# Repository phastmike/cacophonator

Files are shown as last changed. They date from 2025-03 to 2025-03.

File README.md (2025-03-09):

# Cacophonator

This repository contains the [KiCad](https://www.kicad.org/) project of a try at recreating an instance of
**[the cacophonator](https://www.theremin.us/Circuit_Library/cacophonator.html)**
by Arthur Harrison. 

### Build iteration

#### V1 THT

- Using THT (Through-hole) components
- Designed for [JSL 166x116x70mm Box](https://www.leroymerlin.pt/produtos/caixa-estanque-10-boquilhas-153x102x67mm-ip66-cinzento-jsl-15918315.html)

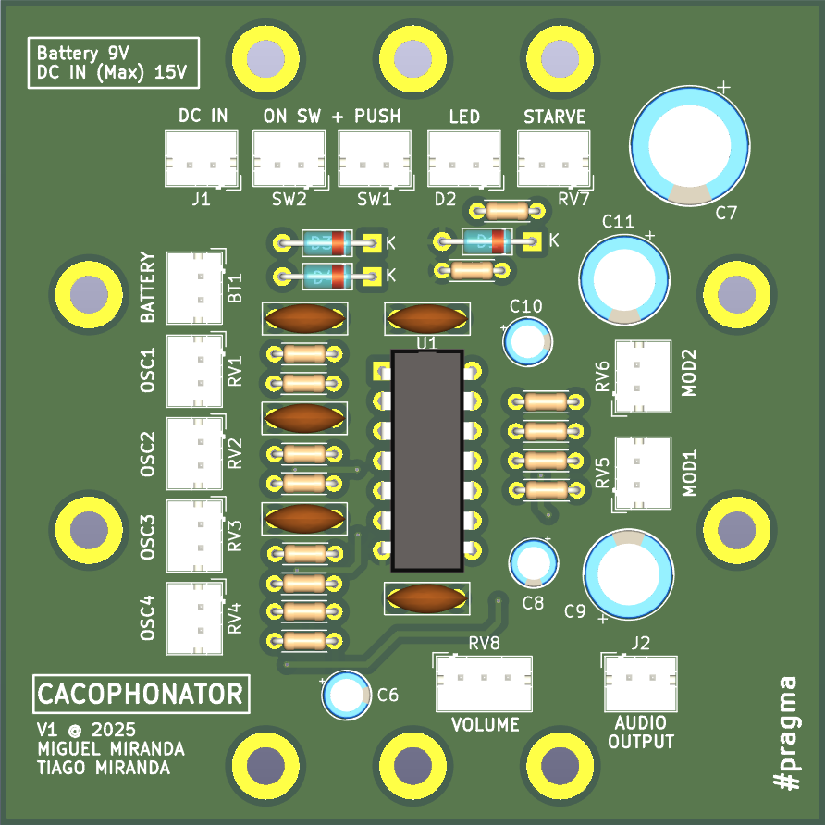
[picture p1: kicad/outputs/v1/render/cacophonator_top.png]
Latest


## Modifications to the original
 
- Added a potentiometer to control the output amplitude (volume)
   - Should be a **logaritmic (log) potentiometer**
- Added DC Input jack with diodes for multiple, concurrent, power sources
   - Battery (9V)
   - DC IN (9 or 12V))

## Notes

Designed with KiCad 9.0 

Top cover layout tryout

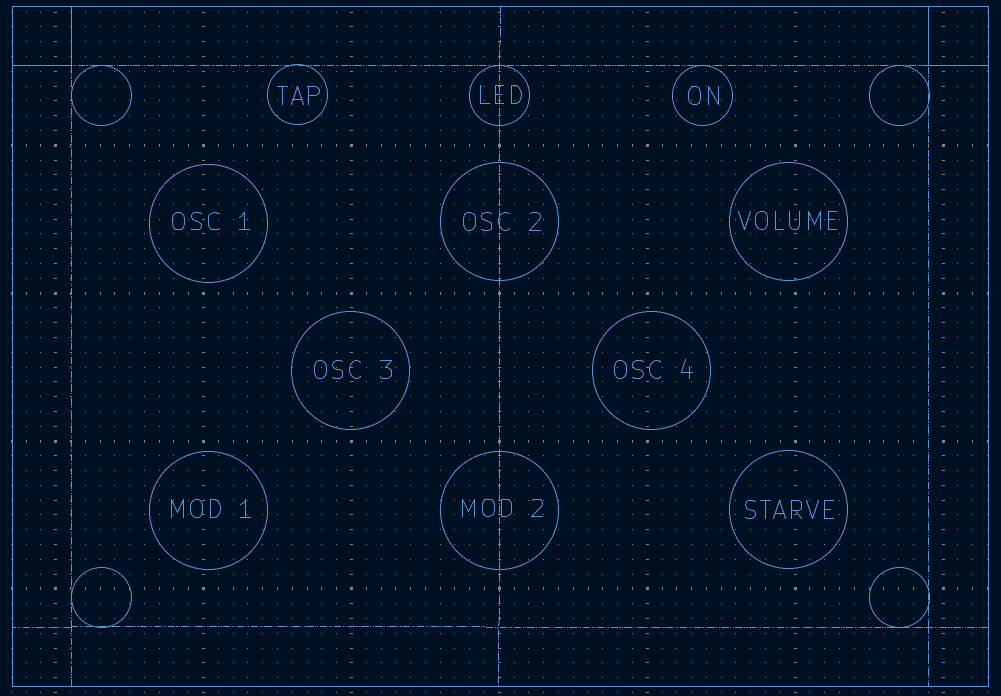
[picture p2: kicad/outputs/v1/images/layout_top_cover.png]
Layout 1


Box (166x116x70mm)

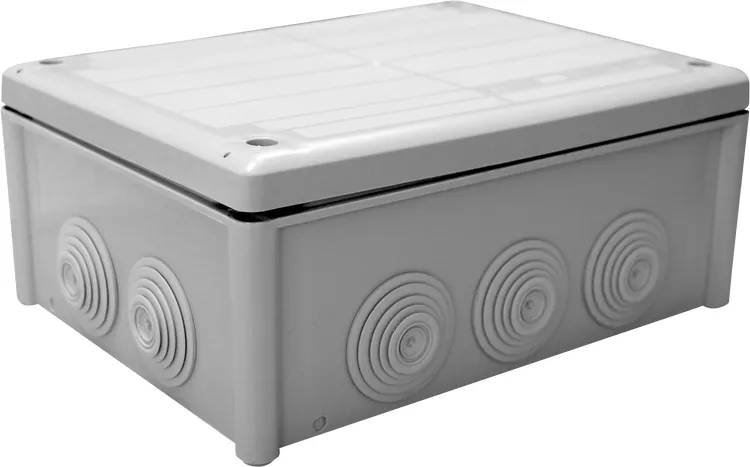
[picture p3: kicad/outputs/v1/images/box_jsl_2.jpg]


### BOM - Bill of Materials

[BOM](icad/outputs/v1/cacophonator-bom.ods)

### Links

- https://www.theremin.us/Circuit_Library/cacophonator.html
- https://syntherjack.net/catophonator/
- https://vitrolxul.mitiendanube.com/productos/cacophonator/
- http://analogmodularsystem.blogspot.com/2014/01/cacophonator-i.html
- https://milwaukeemakerspace.org/2011/09/cacophonator/
- https://beavisaudio.com/projects/cmossynthesizers/
- https://blacblob.qsdf.org/2018/10/03/cacophonator/
- https://static.flickr.com/100/312128991_4e7175fa40.jpg?v=0
- https://www.ti.com/lit/an/slyt336/slyt336.pdf?ts=1739280684395
- https://www.flickr.com/photos/53178019@N00/page2
- https://electro-music.com/forum/post-328159.html
- https://dimsos.dk/cacophonator/cacophonator-take-2-v8/
- https://www.matrixsynth.com/search/label/Cacophonator
- http://www.subtlenoisemaker.com/cacophonator_noir.html

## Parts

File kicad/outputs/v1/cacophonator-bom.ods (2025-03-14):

Reference | Value | Qty | Total | Price Unit | Note | Link
BT1 | 9V | 0 |  |  | JST 2mm | ---
C1,C2 | 2200pF (2.2nF) | 2 | 0.425 | 0.2125 | 15% Disc. AE | AlfaElektor
C3,C4,C5 | 0.01uF (100nF) | 3 | 0.3 | 0.1 |  | https://www.botnroll.com/pt/condensadores/171-condensador-100nf.html
C6,C9,C11 | 22uF | 3 | 0.2175 | 0.0725 | (1.45€/20) | AliExpress
C7 | 2200uF | 1 | 0.184 | 0.184 | (1.84€/10) | AliExpress
C8,C10 | 4.7uF | 2 | 0.375 | 0.1875 | (1.84€/10) | AlfaElektor
D1 | MUR210G* (1N4935G*) | 1 | 0.163 | 0.163 | 1N4934 OPT | https://www.botnroll.com/pt/diodos/919-diodo-retificador-1n4934.html
D2 | LED (Green) | 1 | 0.15 | 0.15 | Apt | https://www.botnroll.com/pt/5mm/2629-led-difuso-5mm.html
D3,D4 | 1N4004* (1N4001-x) | 2 | 0.162 | 0.081 | 1N4001 OPT | https://www.botnroll.com/pt/diodos/1651-diodo-1n4001.html
J1 | 5.5mm/2.1mm DC IN Jack plug | 1 | 0.4 | 0.4 |  | https://www.botnroll.com/pt/alimentacao-dc/1232-socket-dc-supply-male-55mm-25mm-with-onoff-switch-9mm.html
J2 | Jack 6.25mm Chassis Female | 1 | 0.55 | 0.755 | 15% Disc. AE | AlfaElektor
R1,R2,R3,R4,R5,R6,R7,R8,R11,R13 | 10k | 10 | 0.412 | 0.0412 |  | https://www.botnroll.com/pt/resistencias/179-resistencia-10k.html
R10 | 22 | 1 | 0.0422 | 0.0422 | 15% Disc. AE | AlfaElektor
R12,R14 | 100 | 2 | 0.0844 | 0.0422 | 15% Disc. AE | AlfaElektor
R15 | 560 | 1 | 0.0422 | 0.0422 | 15% Disc. AE | AlfaElektor
RV1,RV2,RV3,RV4,RV5,RV6 | 1M | 6 | 2.34 | 0.39 |  | https://www.botnroll.com/pt/potenciometros/5746-potenci-metro-linear-mono-met-lico-1m-125mw-veio-6mm-estriado.html
RV7 | 10k | 1 | 0.39 | 0.39 |  | https://www.botnroll.com/pt/potenciometros/5740-potenci-metro-linear-mono-met-lico-10k-125mw-veio-6mm-estriado.html
RV8 | 100k logaritmic | 1 | 0.39 | 0.39 |  | https://www.botnroll.com/pt/potenciometros/5743-potenci-metro-linear-mono-met-lico-100k-125mw-veio-6mm-estriado.html
SW1 | Switch | 1 | 0.65 | 0.65 | 1A or 3A | https://www.botnroll.com/pt/painel/882-interruptor-2a-250vac-toogle.html
SW2 | Pushbutton | 1 | 0.5 | 0.5 | 1A | https://www.botnroll.com/pt/painel/3154-1065-bot-o-de-press-o-spst-no-1a-250vac-preto.html
U1 | IC 40106 | 1 | 0.85 | 0.85 | 15% Disc. AE | https://www.ti.com/lit/ds/symlink/cd40106b.pdf?ts=1741259708515
DIP IC SOCKET 14PIN | - | 1 | 0.25 | 0.25 |  | https://www.botnroll.com/pt/sockets-ics/190-suporte-ic-14-pinos.html
JST 2mm 2 PIN SOCKET | Various | 13 | 1.8005 | 0.1385 | Incl.socket | https://www.botnroll.com/pt/jst/5029-conector-pcb-jst-ph-2-0mm-2-pinos.html
JST 2mm 2 PIN PLUG | Various | 13 | 0 | 0 |  | https://www.botnroll.com/pt/jst-molex/5024-cabo-jst-ph-2-0mm-20cm-2-pinos.html
JST 2mm 3 PIN SOCKET | Volume | 1 | 0.2 | 0.2 |  | https://www.botnroll.com/pt/jst/5029-3274-conector-pcb-jst-ph-2-0mm-2-pinos.html
JST 2mm 3 PIN PLUG | Volume | 1 | 0.4 | 0.4 |  | https://www.botnroll.com/pt/jst-molex/5024-3255-cabo-jst-ph-2-0mm-20cm-2-pinos.html
BATTERY PLUG 9V | Plug | 1 | 0.4 | 0.4 | 15cm cable | https://www.botnroll.com/pt/6lr61-9v-/738-suporte-para-pilha-9v.html
BATTERY HOLDER | Battery holder | 0 | 0 | 0.5 |  | https://www.botnroll.com/pt/6lr61-9v-/3182-suporte-de-pilhas-9v-com-fios-150mm.html
DC 2.1mm PLUG | DC IN | 0 | 0 | 0.3 |  | https://www.botnroll.com/pt/jack/1234-ficha-femea-alimentacao-dc-55mm-25mm-para-soldar-em-cabo-9mm.html
SCREWS M2.5 |  | 8 | 0.4 | 0.05 | Est. | ---
POTENTIOMETER CAP | VARIOUS OPTIONS | 8 | 2.4 | 0.3 |  | https://www.botnroll.com/pt/potenciometros/4600-knob-bot-o-para-potenci-metro-de-6mm-amarelo.html
LED CHASSIS HOLDER |  | 1 | 0.5 | 0.5 | 8 / 6 mm | ---
PCB (1/10) | PCBWay x10 (13.44€) | 1 | 1.35 | 1.35 |  | https://www.pcbway.com/project/OnlineGerberViewer.html
CAIXA | JSL J160B (166x116x70mm | 1 | 3.19 | 3.19 |  | https://www.leroymerlin.pt/produtos/caixa-estanque-10-boquilhas-153x102x67mm-ip66-cinzento-jsl-15918315.html
 |  |  | 19.5178

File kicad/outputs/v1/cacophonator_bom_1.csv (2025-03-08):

Reference | Value | Qty
BT1 | 9V | 1
C1,C2 | 2200pF | 2
C3,C4,C5 | 0.01uF | 3
C6,C9,C11 | 22uF | 3
C7 | 2200uF | 1
C8,C10 | 4.7uF | 2
D1 | MUR210G* | 1
D2 | LED | 1
D3,D4 | 1N4004* | 2
J1 | Jack-DC | 1
J2 | AUDIO OUTPUT | 1
R1,R2,R3,R4,R5,R6,R7,R8,R11,R13,RV7 | 10k | 11
R10 | 22 | 1
R12,R14 | 100 | 2
R15 | 560 | 1
RV1,RV2,RV3,RV4,RV5,RV6 | 1M | 6
RV8 | 100k log | 1
SW1 | POWER | 1
SW2 | CHARGE | 1
U1 | 40106 | 1

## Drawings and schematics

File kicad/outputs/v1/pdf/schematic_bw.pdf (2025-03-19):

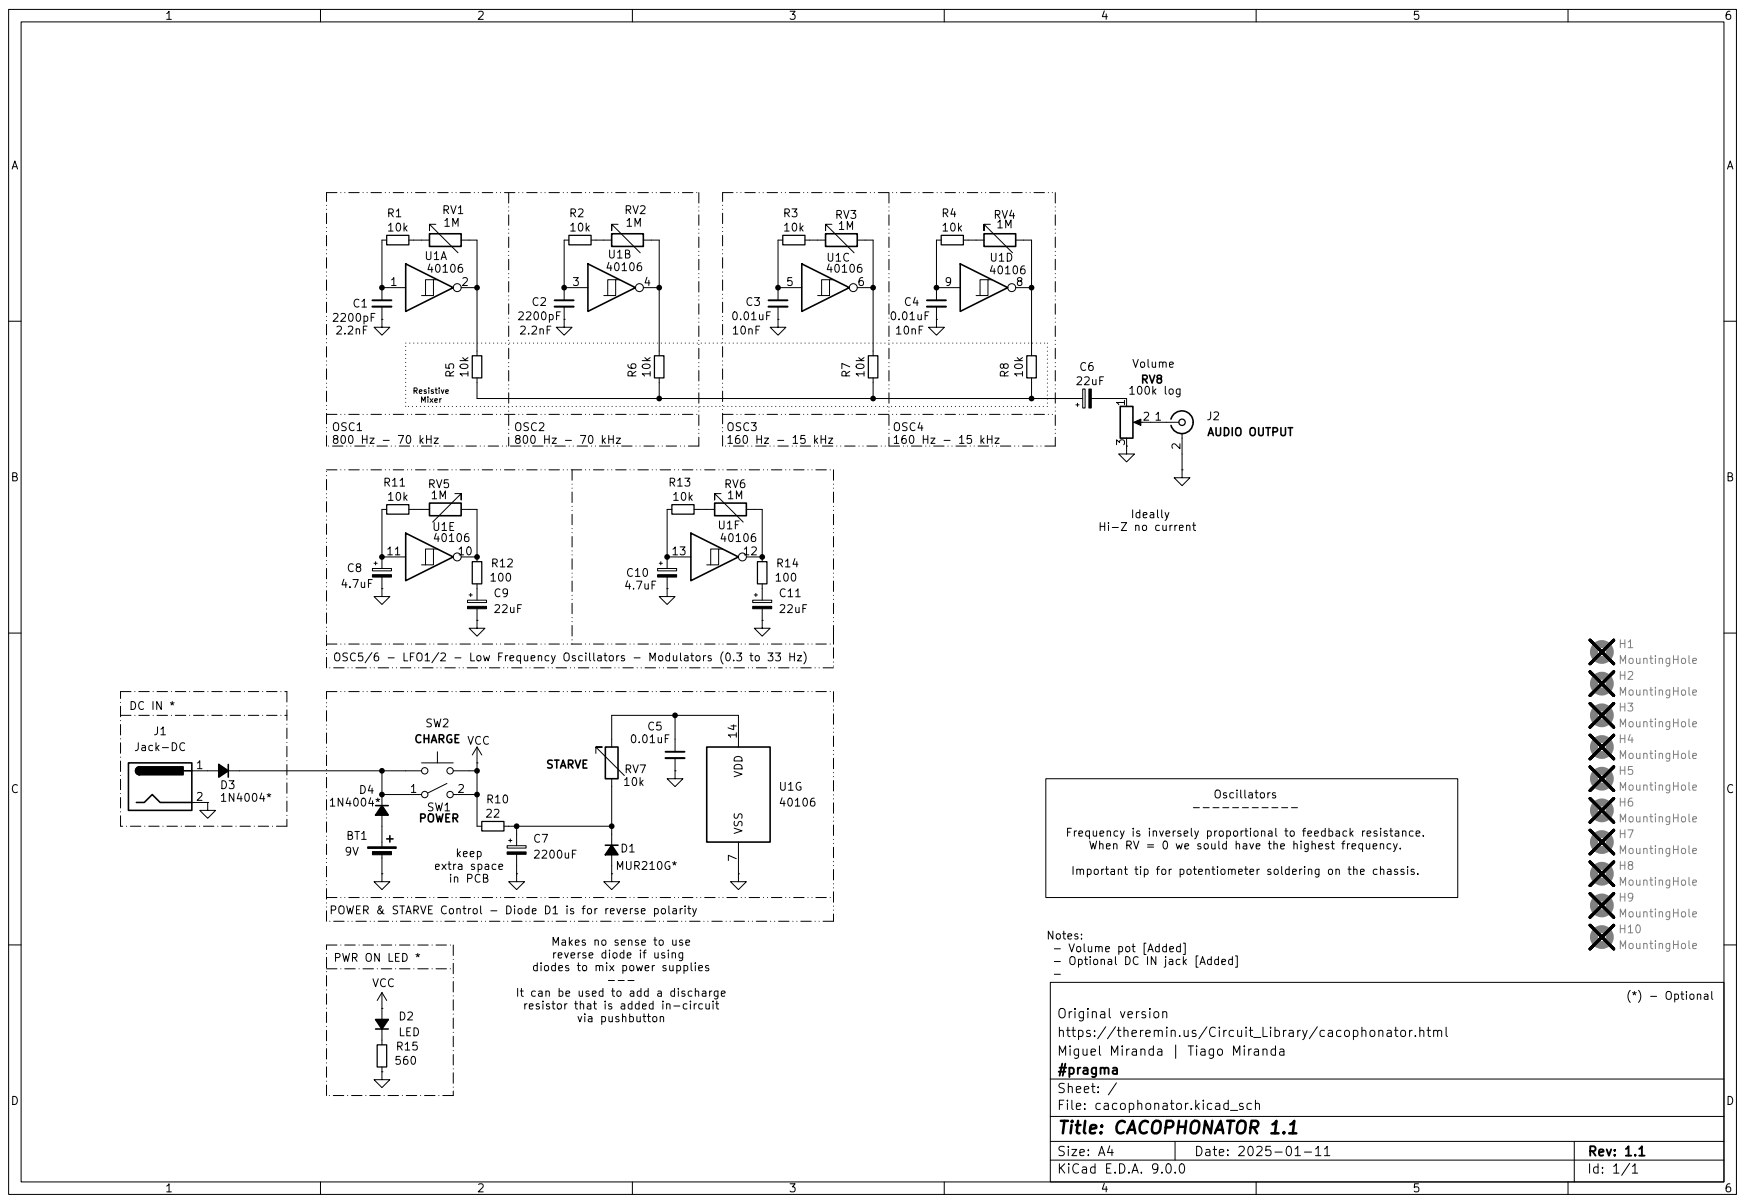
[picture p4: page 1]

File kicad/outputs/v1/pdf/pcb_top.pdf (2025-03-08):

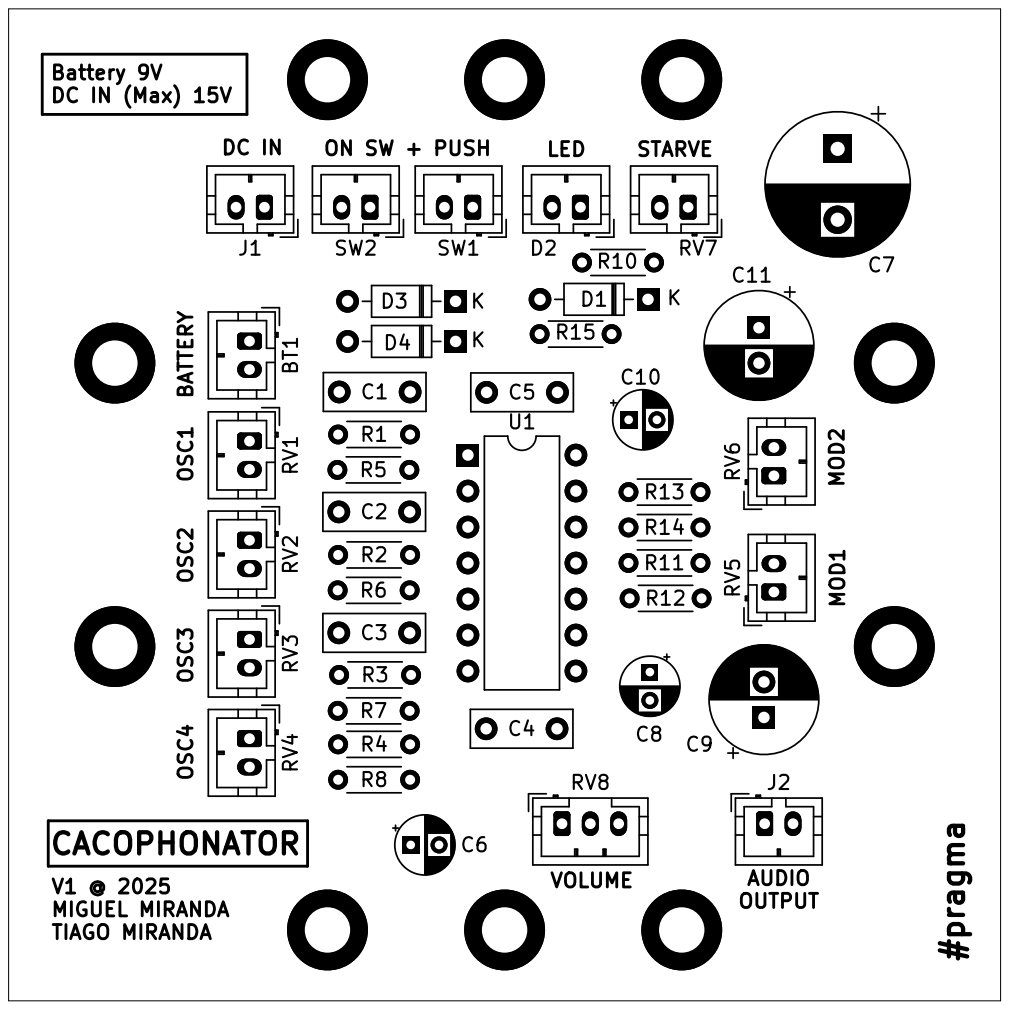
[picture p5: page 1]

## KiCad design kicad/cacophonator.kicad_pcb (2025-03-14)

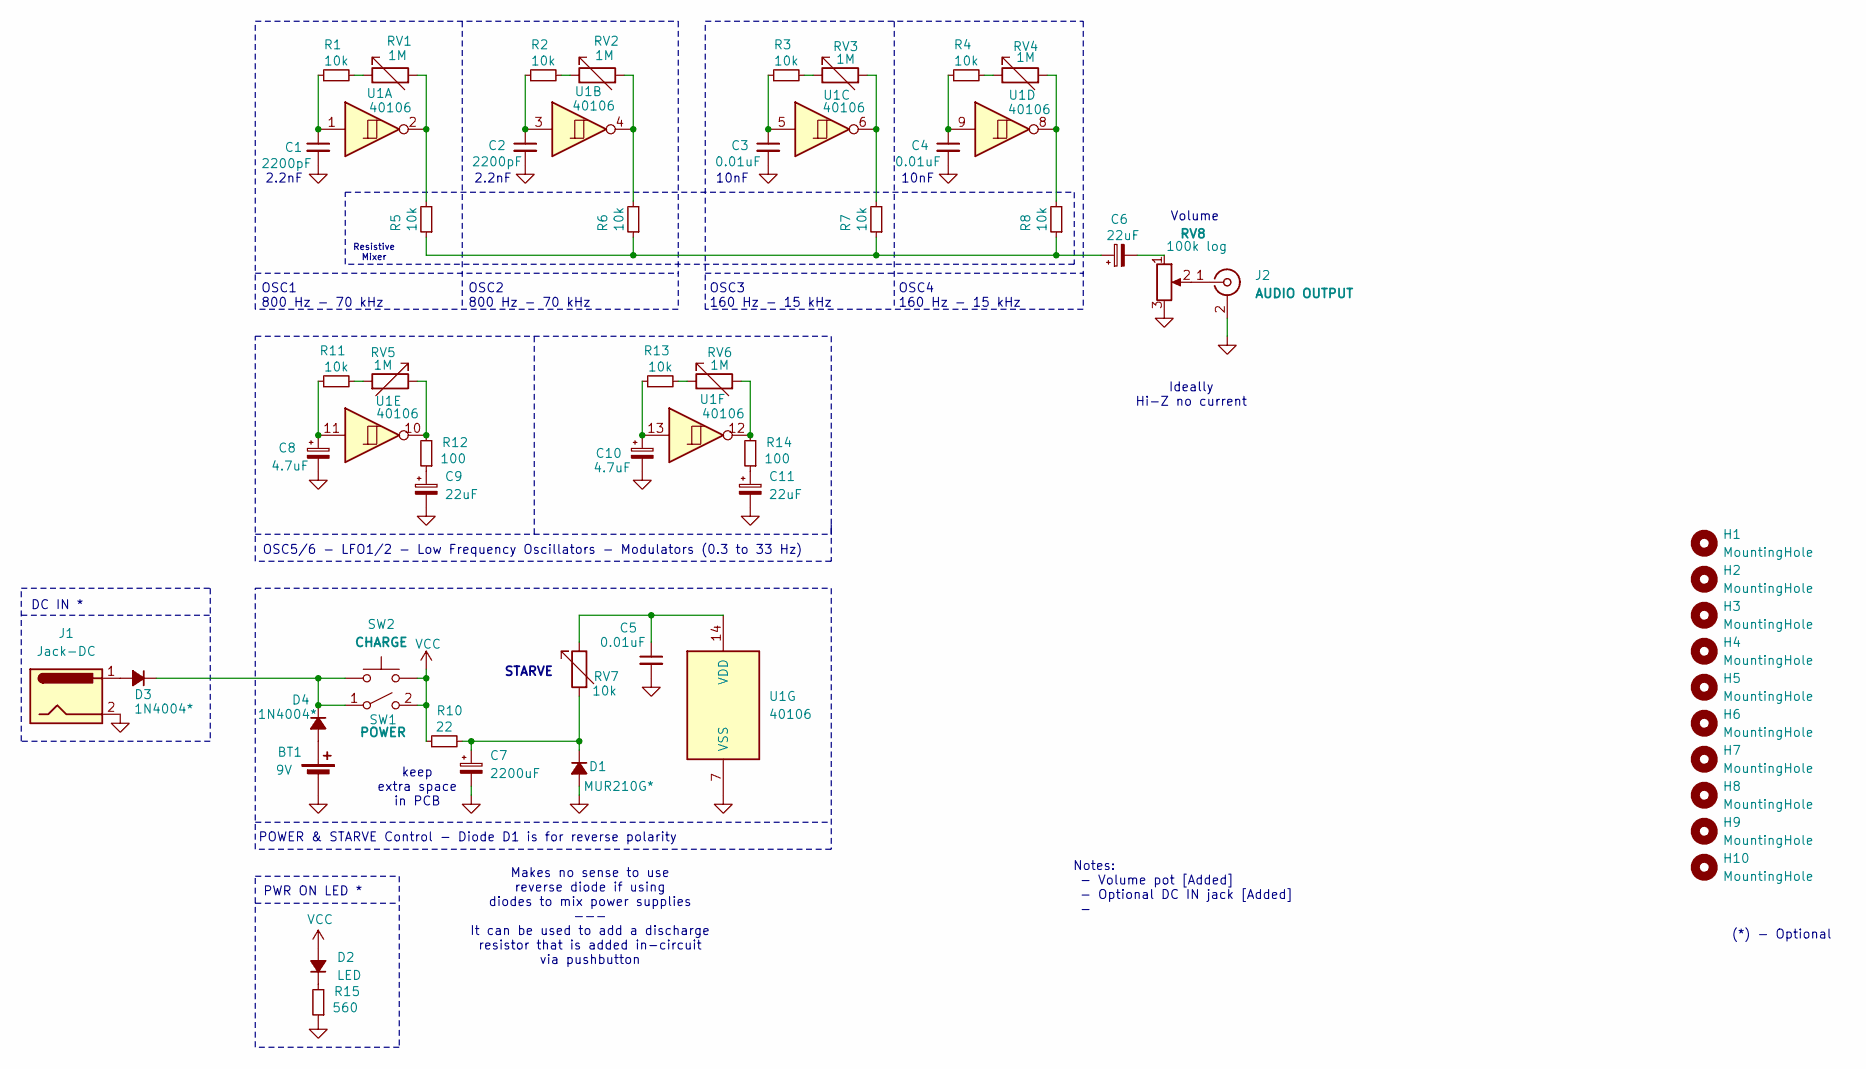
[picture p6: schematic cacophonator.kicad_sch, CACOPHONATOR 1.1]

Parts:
BT1: 9V; JST_PH_B2B-PH-K_1x02_P2.00mm_Vertical
C1, C2: 2200pF; C_Disc_D7.0mm_W2.5mm_P5.00mm
C3, C4, C5: 0.01uF; C_Disc_D7.0mm_W2.5mm_P5.00mm
C6: 22uF; CP_Radial_D4.0mm_P2.00mm
C7: 2200uF; CP_Radial_D10.0mm_P5.00mm
C8, C10: 4.7uF; CP_Radial_D4.0mm_P2.00mm
C9, C11: 22uF; CP_Radial_D7.5mm_P2.50mm
D1: MUR210G*; D_DO-35_SOD27_P7.62mm_Horizontal
D2: LED; JST_PH_B2B-PH-K_1x02_P2.00mm_Vertical
D3, D4: 1N4004*; D_DO-35_SOD27_P7.62mm_Horizontal
H1, H2, H3, H4, H5, H6, H7, H8, H9, H10: MountingHole; MountingHole_3.2mm_M3_ISO7380_Pad
J1: Jack-DC; JST_PH_B2B-PH-K_1x02_P2.00mm_Vertical
J2: AUDIO OUTPUT; JST_PH_B2B-PH-K_1x02_P2.00mm_Vertical
R1, R2, R3, R4, R5, R6, R7, R8, R11, R13: 10k; R_Axial_DIN0204_L3.6mm_D1.6mm_P5.08mm_Horizontal
R10: 22; R_Axial_DIN0204_L3.6mm_D1.6mm_P5.08mm_Horizontal
R12, R14: 100; R_Axial_DIN0204_L3.6mm_D1.6mm_P5.08mm_Horizontal
R15: 560; R_Axial_DIN0204_L3.6mm_D1.6mm_P5.08mm_Horizontal
RV1, RV2, RV3, RV4, RV5, RV6: 1M; JST_PH_B2B-PH-K_1x02_P2.00mm_Vertical
RV7: 10k; JST_PH_B2B-PH-K_1x02_P2.00mm_Vertical
RV8: 100k log; JST_PH_B3B-PH-K_1x03_P2.00mm_Vertical
SW1: POWER; JST_PH_B2B-PH-K_1x02_P2.00mm_Vertical
SW2: CHARGE; JST_PH_B2B-PH-K_1x02_P2.00mm_Vertical
U1: 40106; DIP-14_W7.62mm

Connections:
GND: BT1.2 (-), C1.2, C2.2, C3.2, C4.2, C5.2, C7.2, C8.2, C9.2, C10.2, C11.2, D1.2 (A), J1.2, J2.2 (Ext), R15.1, RV8.3, U1.7 (VSS)
unnamed: BT1.1 (+), D4.2 (A)
unnamed: C1.1, R1.1, U1.1
unnamed: C2.1, R2.1, U1.3
unnamed: C3.1, R3.1, U1.5
unnamed: C4.1, R4.1, U1.9
unnamed: C6.1, R5.1, R6.1, R7.1, R8.1
unnamed: C6.2, RV8.1
unnamed: C8.1, R11.1, U1.11
unnamed: C9.1, R12.1
unnamed: C10.1, R13.1, U1.13
unnamed: C11.1, R14.1
unnamed: C7.1, D1.1 (K), R10.2, RV7.2
unnamed: D2.1 (K), R15.2
unnamed: D3.2 (A), J1.1
unnamed: D3.1 (K), D4.1 (K), SW1.1 (A), SW2.1
unnamed: J2.1 (In), RV8.2
unnamed: R1.2, RV1.1
unnamed: R2.2, RV2.1
unnamed: R3.2, RV3.1
unnamed: R4.2, RV4.1
unnamed: R5.2, RV1.2, U1.2
unnamed: R6.2, RV2.2, U1.4
unnamed: R7.2, RV3.2, U1.6
unnamed: R8.2, RV4.2, U1.8
unnamed: R11.2, RV5.2
unnamed: R12.2, RV5.1, U1.10
unnamed: R13.2, RV6.1
unnamed: R14.2, RV6.2, U1.12
unnamed: C5.1, RV7.1, U1.14 (VDD)
VCC: D2.2 (A), R10.1, SW1.2 (B), SW2.2

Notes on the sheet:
OSC4 160 Hz - 15 kHz
Volume
10nF
Ideally Hi-Z no current
POWER & STARVE Control - Diode D1 is for reverse polarity
2.2nF
(*) - Optional
Resistive Mixer
DC IN *
STARVE
keep extra space in PCB
Makes no sense to use reverse diode if using diodes to mix power supplies --- It can be used to add a discharge resistor that is added in-circuit via pushbutton
PWR ON LED *
OSC1 800 Hz - 70 kHz
Notes: - Volume pot [Added] - Optional DC IN jack [Added] -
OSC3 160 Hz - 15 kHz
OSC2 800 Hz - 70 kHz
OSC5/6 - LFO1/2 - Low Frequency Oscillators - Modulators (0.3 to 33 Hz)

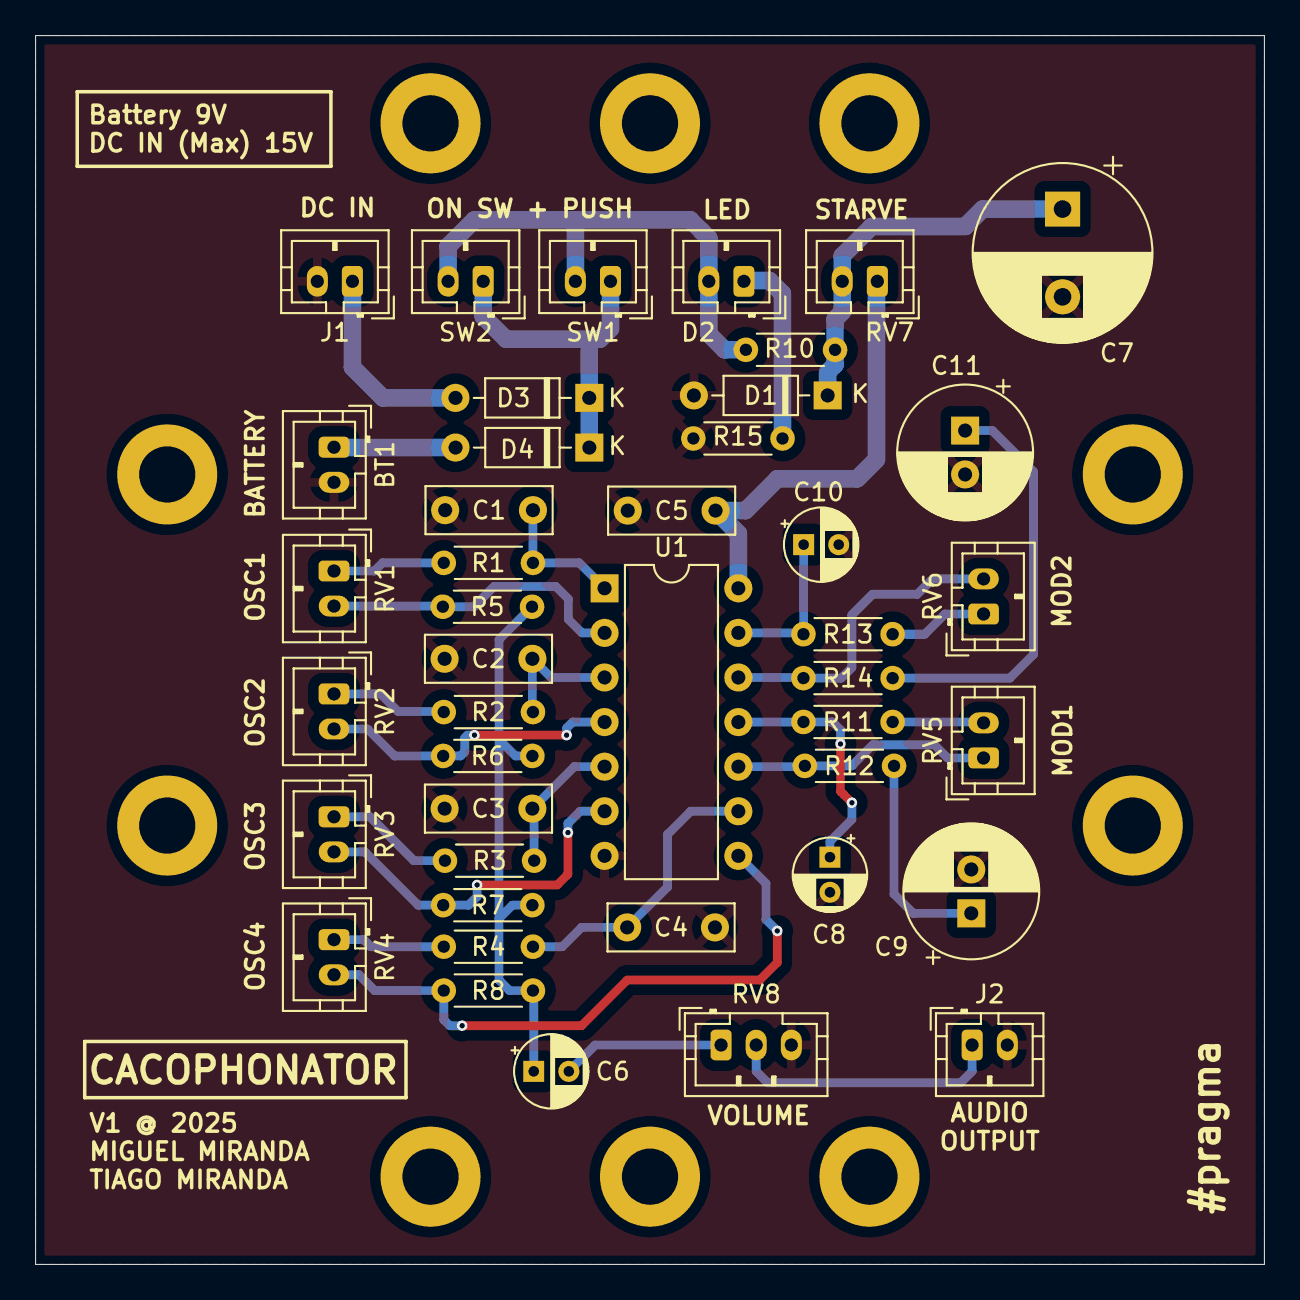
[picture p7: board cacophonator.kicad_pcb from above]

Board: 2 copper layers, 70.0 x 70.0 mm, 53 parts (0 on the bottom side), 31 nets.

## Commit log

2025-03-08 Added pdf folder with schematic and pcb layout
    [cacophonator.kicad_pcb]
2025-03-08 updated schematic
2025-03-08 Minor tweaks
    [cacophonator.kicad_pcb]
2025-03-08 BOM added to README
    [cacophonator-bom.ods]
2025-03-09 BOM Changes + minor tweaks
    [cacophonator-bom.ods, cacophonator.kicad_pcb]
2025-03-09 Changed switch/push position on the layout
2025-03-14 Minor updates
    [cacophonator-bom.ods, cacophonator.kicad_pcb, cacophonator.kicad_sch]
2025-03-19 Added info to schematic
    [cacophonator.kicad_sch]
